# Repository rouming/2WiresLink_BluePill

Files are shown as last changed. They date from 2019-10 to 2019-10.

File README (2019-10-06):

This is DC low voltage (up to 60v) PLC modem based on the following
schematics https://www.radiolocman.com/shem/schematics.html?di=148255
with only one modification for small 500k carrier frequency: C3 was
changed from 100pF to 1nF.

Firmware is written for STM32F103 BluePill board.  Modem PCB is designed
in such a way that BluePill can be directly pluged in using hardware
USART1 support.

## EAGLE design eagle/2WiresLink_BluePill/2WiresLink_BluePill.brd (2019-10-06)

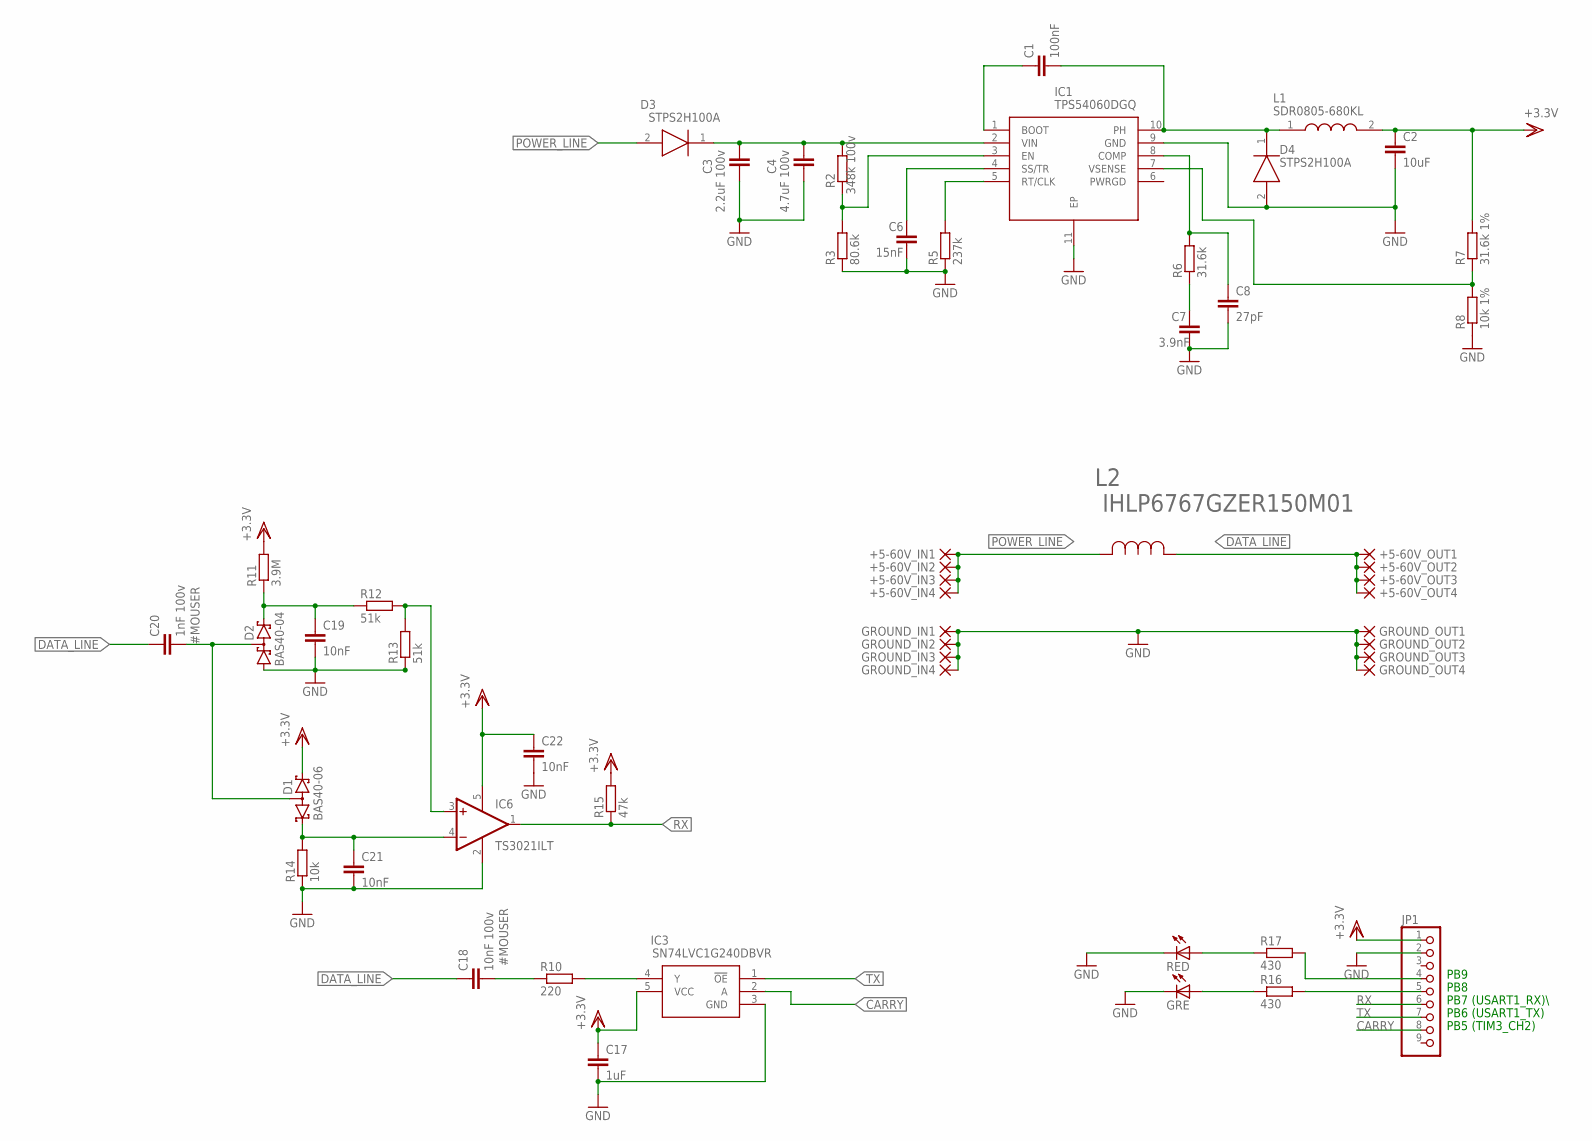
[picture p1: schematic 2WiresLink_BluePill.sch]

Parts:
+5-60V_IN1, +5-60V_IN2, +5-60V_IN3, +5-60V_IN4, +5-60V_OUT1, +5-60V_OUT2, +5-60V_OUT3, +5-60V_OUT4: PAD-0820-S; 0820-S
C1: 100nF; C0603; MPN C0603C104K5RECAUTO
C2: 10uF; C0603; MPN GRM188R61A106KE69D
C3: 2.2uF 100v; C1210; MPN C3225X7R2A225K230AB
C4: 4.7uF 100v; C1210; MPN CGA6M3X7S2A475K200AB
C6: 15nF; C0603; MPN C0603C153K5RACTU
C7: 3.9nF; C0603; MPN GCM1885C1H392JA16D
C8: 27pF; C0603; MPN 06035A270JAT2A
C17: 1uF; C0603; MPN 0603YD105KAT2A
C18: 10nF 100v; C0603; MPN GCM188R72A103KA37D
C19, C22: 10nF; C0603; MPN C0603C103K5RACAUTO7411
C20: 1nF 100v; C0603; MPN 06031C102KAT2A
C21: 10nF; C0603
D1: BAS40-06; SOT23; MPN BAS40-06-E3-08
D2: BAS40-04; SOT23; MPN BAS40-04-7-F
D3, D4: STPS2H100A; DIOM5126X265N; MPN STPS2H100A
GRE: GRE; CHIP-LED0805; MPN SML-LXT0805GW-TR
GROUND_IN1, GROUND_IN2, GROUND_IN3, GROUND_IN4: PAD-0820-S; 0820-S
GROUND_OUT1, GROUND_OUT2, GROUND_OUT3, GROUND_OUT4: PAD-0820-S; 0820-S
IC1: TPS54060DGQ; SOP50P490X110-11N; MPN TPS54060DGQR
IC3: SN74LVC1G240DBVR; SOT95P280X145-5N; MPN SN74LVC1G240DBVR
IC6: TS3021ILT; SOT95P280X145-5N; MPN TS3021ILT
JP1: PINHD-1X9; 1X09-BIG
L1: SDR0805-680KL; MPN SDR0805-680KL
L2: IHLP6767GZER150M01; IND_IHLP-6767GZ; MPN IHLP6767GZER150M01
R2: 348k 100v; R0603; MPN RG1608P-3483-D-T5
R3: 80.6k; R0603; MPN CRCW060380K6FKEA
R5: 237k; R0603; MPN AC0603FR-07237KL
R6: 31.6k; R0603; MPN AC0603FR-0731K6L
R7: 31.6k 1%; R0603; MPN AC0603FR-0731K6L
R8: 10k 1%; R0603; MPN CRCW060310K0FKEAC
R10: 220; R0603; MPN RC0603FR-07220RL
R11: 3.9M; R0603; MPN RC0603FR-073M9L
R12, R13: 51k; R0603; MPN RC0603FR-0751KL
R14: 10k; R0603; MPN CRCW060310K0FKEAC
R15: 47k; R0603; MPN RC0603FR-0747KL
R16, R17: 430; R0603; MPN RC0603FR-07430RL
RED: RED; CHIP-LED0805; MPN SML-LXT0805IW-TR

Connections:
CARRY: IC3.2 (A), JP1.8
DATA_LINE: +5-60V_OUT1.P$1, +5-60V_OUT2.P$1, +5-60V_OUT3.P$1, +5-60V_OUT4.P$1, C18.1, C20.1, L2.1
GND: C2.2, C3.2, C4.2, C6.2, C7.2, C8.2, C17.2, C19.2, C21.2, C22.2, D2.1 (A1), D4.2 (A), GRE.C, GROUND_IN1.P$1, GROUND_IN2.P$1, GROUND_IN3.P$1, GROUND_IN4.P$1, GROUND_OUT1.P$1, GROUND_OUT2.P$1, GROUND_OUT3.P$1, GROUND_OUT4.P$1, IC1.9 (GND), IC1.11 (EP), IC3.3 (GND), IC6.2 (V-), JP1.2, R3.1, R5.1, R8.1, R13.1, R14.1, RED.C
unnamed: C1.2, D4.1 (K), IC1.10 (PH), L1.1
unnamed: C1.1, IC1.1 (BOOT)
unnamed: C7.1, R6.1
unnamed: C8.1, IC1.8 (COMP), R6.2
unnamed: IC1.3 (EN), R2.1, R3.2
unnamed: IC1.7 (VSENSE), R7.1, R8.2
unnamed: C3.1, C4.1, D3.1 (K), IC1.2 (VIN), R2.2
unnamed: C6.1, IC1.4 (SS/TR)
unnamed: IC1.5 (RT/CLK), R5.2
unnamed: JP1.4, R17.2
unnamed: JP1.5, R16.2
unnamed: IC3.4 (Y), R10.2
unnamed: C18.2, R10.1
unnamed: C19.1, D2.2 (C2), R11.1, R12.1
unnamed: IC6.3 (+IN), R12.2, R13.2
unnamed: C20.2, D1.3 (AA), D2.3 (C1A2)
unnamed: C21.1, D1.1 (K1), IC6.4 (-IN), R14.2
unnamed: GRE.A, R16.1
unnamed: R17.1, RED.A
POWER_LINE: +5-60V_IN1.P$1, +5-60V_IN2.P$1, +5-60V_IN3.P$1, +5-60V_IN4.P$1, D3.2 (A), L2.2
RX: IC6.1 (OUT), JP1.6, R15.1
TX: IC3.1 (!OE), JP1.7
VDD: C2.1, C17.1, C22.1, D1.2 (K2), IC3.5 (VCC), IC6.5 (V+), JP1.1, L1.2, R7.2, R11.2, R15.2

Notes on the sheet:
PB7 (USART1_RX)\
PB6 (USART1_TX)
PB5 (TIM3_CH2)
PB9
PB8

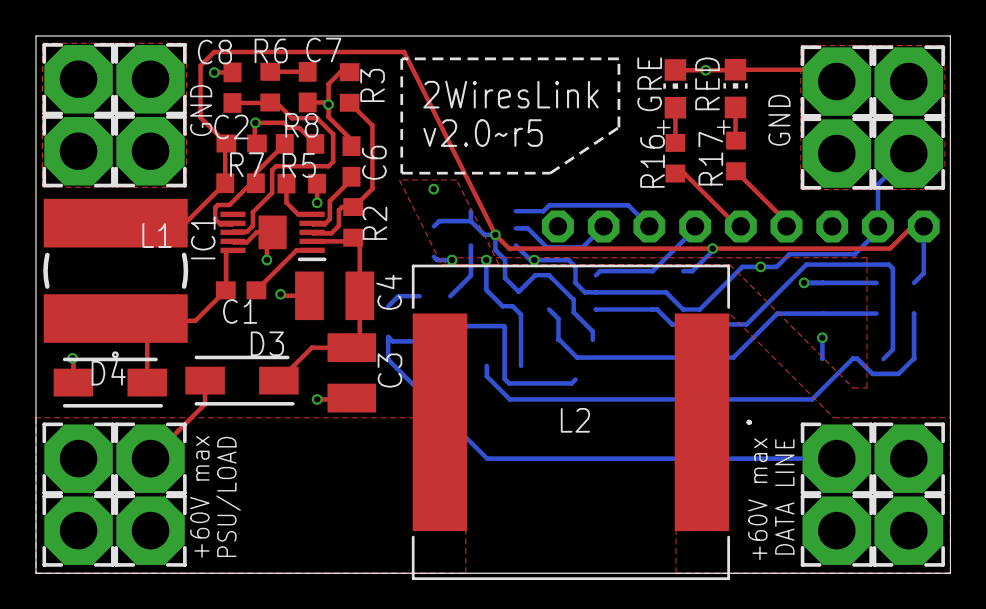
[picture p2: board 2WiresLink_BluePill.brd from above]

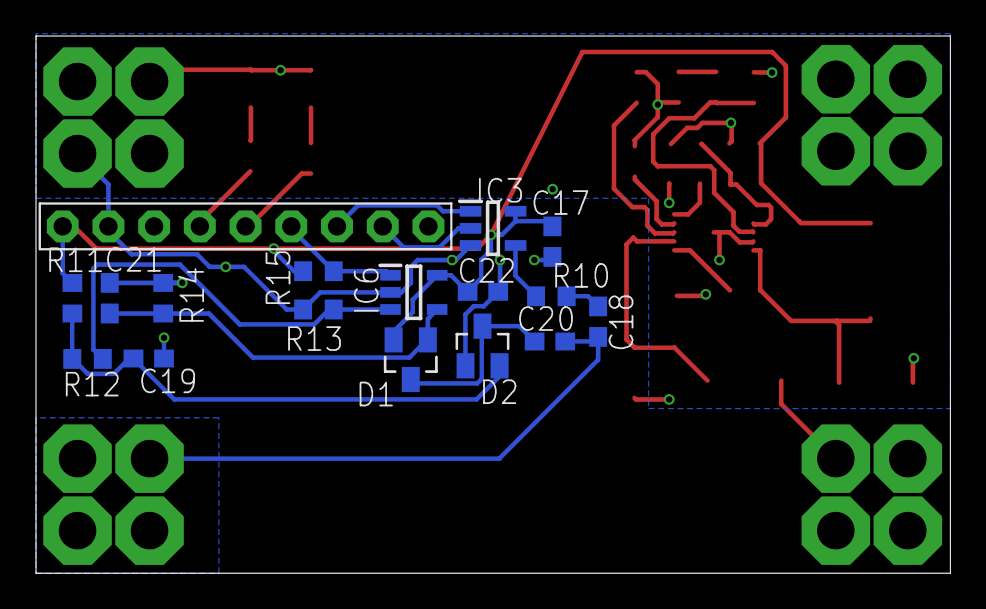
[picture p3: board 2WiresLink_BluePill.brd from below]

Board: 2 copper layers, 50.8 x 29.8 mm, 55 parts (17 on the bottom side), 26 nets.

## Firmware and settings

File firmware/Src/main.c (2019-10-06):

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

/* Includes ------------------------------------------------------------------*/
#include "main.h"

/* USER CODE BEGIN Includes */
#include "usart.h"
/* USER CODE END Includes */

TIM_HandleTypeDef htim3;

UART_HandleTypeDef huart1;

void SystemClock_Config(void);
static void MX_GPIO_Init(void);
static void MX_TIM3_Init(void);
static void MX_USART1_UART_Init(void);
/* USER CODE BEGIN 0 */

struct pkt {
	uint32_t seq;
};

struct ctx {
	struct pkt pkt;
	uint32_t seq;
	uint32_t seq_inited;
};

static int handle_request(void *ctx_, uint8_t rx_len,
			  void **tx_buf_out, uint8_t *tx_len_out)
{
	struct ctx *ctx = ctx_;

	if (rx_len != sizeof(ctx->pkt))
		/* Wrong length */
		return -1;

	if (ctx->seq_inited) {
		int correct_seq = (ctx->seq + 1 == ctx->pkt.seq);

		if (!correct_seq) {
			ctx->seq_inited = 0;
			return -1;
		}
	}
	ctx->seq = ctx->pkt.seq;
	ctx->seq_inited = 1;

	*tx_buf_out = (uint8_t *)&ctx->pkt;
	*tx_len_out = sizeof(ctx->pkt);

	return 0;
}

static int handle_response(void *ctx_, uint8_t rx_len)
{
	struct ctx *ctx = ctx_;

	if (rx_len != sizeof(ctx->pkt))
		/* Wrong length */
		return -1;

	return (ctx->seq == ctx->pkt.seq ? 0 : -1);
}

/* USER CODE END 0 */

/**
  * @brief  The application entry point.
  * @retval int
  */
int main(void)
{
  /* USER CODE BEGIN 1 */
  struct ctx ctx = {
	  .seq = 0,
  };
  /* USER CODE END 1 */

  /* MCU Configuration--------------------------------------------------------*/

  /* Reset of all peripherals, Initializes the Flash interface and the Systick. */
  HAL_Init();

  /* Configure the system clock */
  SystemClock_Config();

  /* Initialize all configured peripherals */
  MX_GPIO_Init();
  MX_TIM3_Init();
  MX_USART1_UART_Init();
  /* USER CODE BEGIN 2 */
  USART_Init(&huart1, &htim3, TIM_CHANNEL_2);
  /* USER CODE END 2 */

  /* Infinite loop */
  /* USER CODE BEGIN WHILE */
  while (1) {
	  uint16_t led;
	  int ret;

	  HAL_GPIO_TogglePin(GPIOC, BP_LED_Pin);

	  if (HAL_GPIO_ReadPin(GPIOB, MASTER_LINK_Pin)) {
		  /* Master */
		  ctx.pkt.seq = ++ctx.seq;

		  ret = USART_SendRecvSync(&ctx.pkt, sizeof(ctx.pkt), /* tx */
					   &ctx.pkt, sizeof(ctx.pkt), /* rx */
					   REPEAT_TX_REQS_x5);
		  if (ret >= 0)
			  ret = handle_response(&ctx, ret);
	  } else {
		  /* Slave */

		  ret = USART_RecvSendSync(&ctx,
					   &ctx.pkt, sizeof(ctx.pkt), /* rx */
					   handle_request);
	  }

	  led = (!ret ? GREEN_LED_Pin : RED_LED_Pin);
	  HAL_GPIO_WritePin(GPIOB, led, GPIO_PIN_SET);
	  HAL_Delay(10);
	  HAL_GPIO_WritePin(GPIOB, led, GPIO_PIN_RESET);
	  HAL_Delay(10);

	  USART_Process();
  }
    /* USER CODE END WHILE */

}

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


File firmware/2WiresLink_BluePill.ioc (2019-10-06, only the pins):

Mcu.UserName=STM32F103C8Tx
PA13.Signal=SYS_JTMS-SWDIO
PA14.Signal=SYS_JTCK-SWCLK
PB2.GPIO_Label=MASTER_LINK
PB2.Signal=GPIO_Input
PB5.Signal=S_TIM3_CH2
PB6.Signal=USART1_TX
PB7.Signal=USART1_RX
PB8.GPIO_Label=GREEN_LED
PB8.Signal=GPIO_Output
PB9.GPIO_Label=RED_LED
PB9.Signal=GPIO_Output
PC13-TAMPER-RTC.GPIO_Label=BP_LED
PC13-TAMPER-RTC.Signal=GPIO_Output
PD0-OSC_IN.Signal=RCC_OSC_IN
PD1-OSC_OUT.Signal=RCC_OSC_OUT

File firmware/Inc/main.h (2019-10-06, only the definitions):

#define BP_LED_Pin GPIO_PIN_13
#define BP_LED_GPIO_Port GPIOC
#define MASTER_LINK_Pin GPIO_PIN_2
#define MASTER_LINK_GPIO_Port GPIOB
#define GREEN_LED_Pin GPIO_PIN_8
#define GREEN_LED_GPIO_Port GPIOB
#define RED_LED_Pin GPIO_PIN_9
#define RED_LED_GPIO_Port GPIOB

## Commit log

2019-10-06 Initial commit.
    [2WiresLink_BluePill.brd, 2WiresLink_BluePill.sch]
2019-10-06 firmware: decrease carry frequency and baud rate
    Decrease carry frequency from 500k to 100k and
    baud rate from 19200 to 4800 in order to increase
    cable length and packet delivery under high load.
2019-10-06 eagle: increase C21 capacity from 1nF to 10nF
    In previous commit carry frequency and baud rate was decreased,
    C21 capacity should be increased.
    [2WiresLink_BluePill.brd, 2WiresLink_BluePill.sch]

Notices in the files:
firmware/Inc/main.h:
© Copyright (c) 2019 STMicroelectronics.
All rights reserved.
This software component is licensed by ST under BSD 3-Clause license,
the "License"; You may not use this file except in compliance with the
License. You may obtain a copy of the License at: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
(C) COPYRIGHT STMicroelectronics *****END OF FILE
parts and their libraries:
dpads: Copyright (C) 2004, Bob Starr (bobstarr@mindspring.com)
